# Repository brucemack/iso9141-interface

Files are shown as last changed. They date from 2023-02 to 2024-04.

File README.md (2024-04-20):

Overview
========
This is a KiCad project for a simple ISO-9141 interface board.  This allows a microcontroller to be interfaced to car's ISO-9141 (OBD2) port.

Please see related firmware projects:

* [The OBDII Reader](https://github.com/brucemack/hello-obd2)
* [The ECU Simulator](https://github.com/brucemack/ecu-sim)

[Here is the official ISO standard document](https://cdn.standards.iteh.ai/samples/16737/e6b719fd44c345a792656f6d19e6cee4/ISO-9141-1989.pdf) that explains all of the details of this interface. What makes this interesting is that the transmit/receive to/from the vehicle all happens on a single wire.

Send any questions to bruce at mackinnon dot com.

Interfaces (V2)
===============

J1 is the connection to the vehicle:
* Pin 1 - 12V battery power
* Pin 2 - KLINE
* Pin 3 - Ground

J2 is the connector to the microcontroller:
* Pin 1 - Data transmit (data from controller to vehicle)
* Pin 2 - Data receive (data from vehicle to controller)
* Pin 3 - Control line which allow the KLINE to be pulled low for the purposes of signalling
* Pin 4 - An indicator LED that can be used by the controller
* Pin 5 - +5V regulated power for controller
* Pin 6 - Ground

Hardware
========

The V2 PCB:

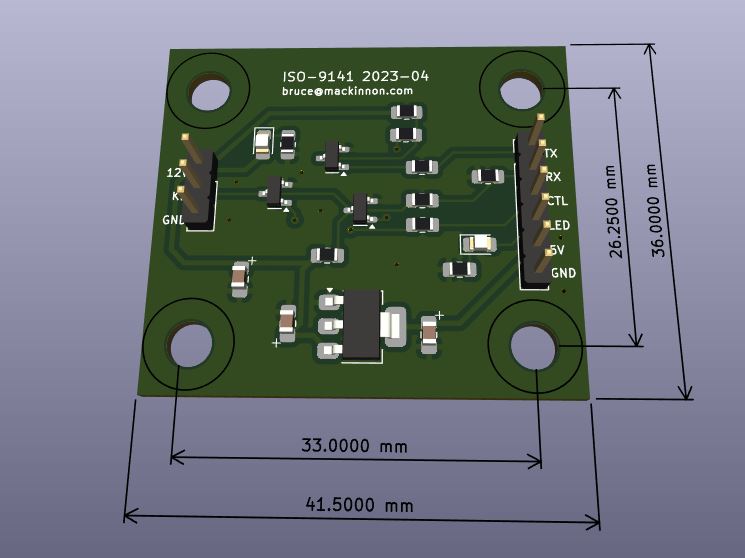
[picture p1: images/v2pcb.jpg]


Here's what it looks like in real life (V1):

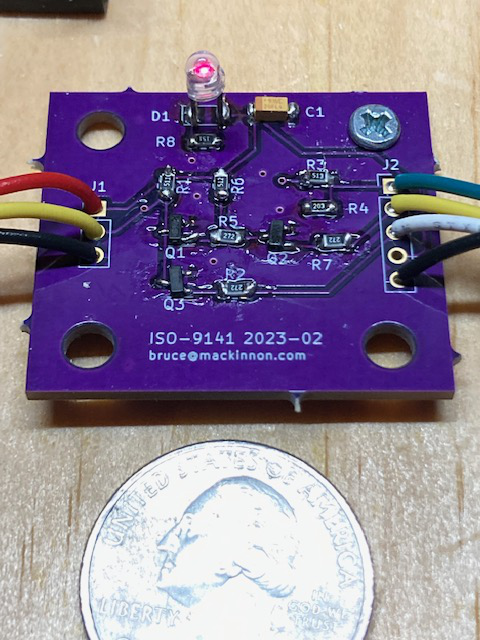
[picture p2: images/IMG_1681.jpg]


Connector Notes
===============

The scanner/instrument uses a SAE J1962 connector (male)
* [Cable](https://www.amazon.com/iKKEGOL-Connector-Diagnostic-Extension-Pigtail/dp/B0828YHWFG)
* [Just the Connector](https://www.sparkfun.com/products/9911)
* [Connector](https://www.amazon.com/Elecbee-Automobile-Connector-Shell-Diagnostic/dp/B0CKMSXCBY)

The vehicle uses a J1962F female connector like this: https://www.amazon.com/Goliton-Connection-Connector-Harness-Assembled/dp/B09NBWQLMQ

Copyright
=========

Copyright (C) 2024 - Bruce MacKinnon

This work is covered under the terms of the GNU Public License (V3). Please consult the LICENSE file for more information.

This work is being made available for non-commercial use. Redistribution, commercial use or sale of any part is prohibited.

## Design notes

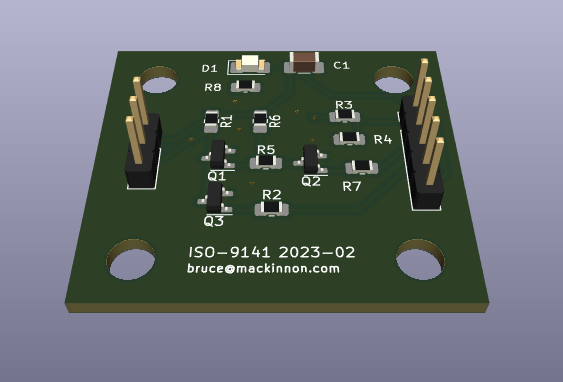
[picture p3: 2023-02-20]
images/SS1.png

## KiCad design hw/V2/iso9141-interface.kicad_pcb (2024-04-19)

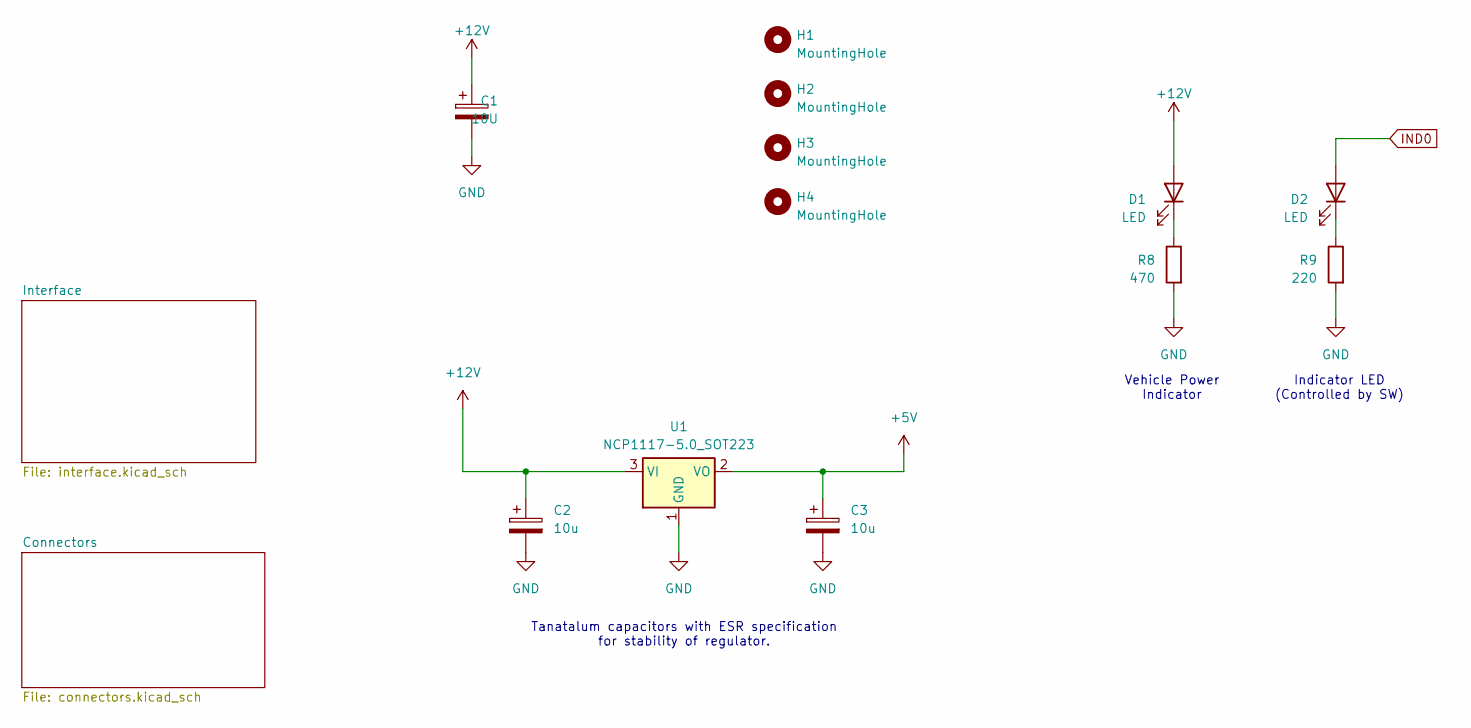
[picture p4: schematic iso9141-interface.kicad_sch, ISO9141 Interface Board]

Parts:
C1: 10U; CPOL_0805_2012Metric_Pad1.18x1.45mm_HandSolder
C2, C3: 10u; CPOL_0805_2012Metric_Pad1.18x1.45mm_HandSolder
D1, D2: LED; LED_0805_2012Metric_Pad1.15x1.40mm_HandSolder
H1, H2, H3, H4: MountingHole; MountingHole_4.3mm_M4
R8: 470; R_0805_2012Metric_Pad1.20x1.40mm_HandSolder
R9: 220; R_0805_2012Metric_Pad1.20x1.40mm_HandSolder
U1: NCP1117-5.0_SOT223; SOT-223-3_TabPin2

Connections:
+5V: C3.1, U1.2 (VO); also elsewhere on the board
+12V: C1.1, C2.1, D1.2 (A), U1.3 (VI); also elsewhere on the board
GND: C1.2, C2.2, C3.2, R8.2, R9.2, U1.1 (GND); also elsewhere on the board
IND0: D2.2 (A); also elsewhere on the board
unnamed: D1.1 (K), R8.1
unnamed: D2.1 (K), R9.1

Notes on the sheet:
Tanatalum capacitors with ESR specification for stability of regulator.
Indicator LED (Controlled by SW)
Vehicle Power Indicator

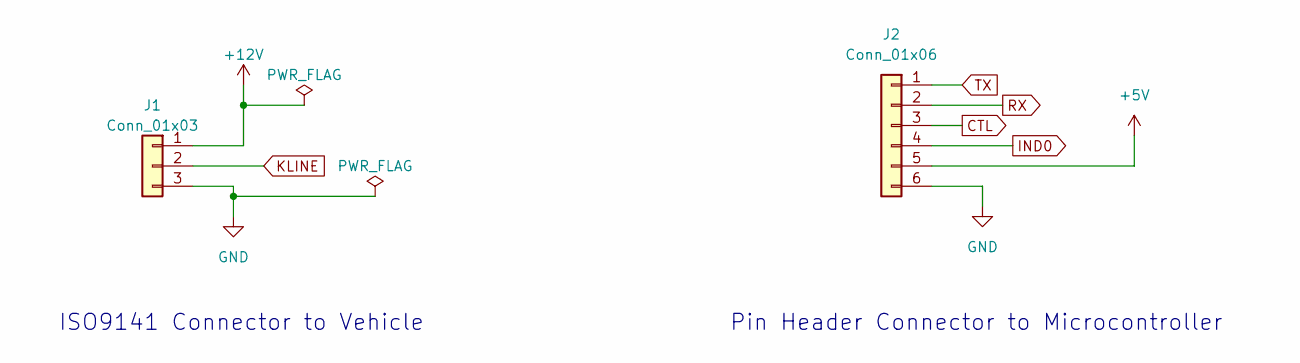
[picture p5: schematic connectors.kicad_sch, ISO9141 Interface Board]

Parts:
J1: Conn_01x03; PinHeader_1x03_P2.54mm_Vertical
J2: Conn_01x06; PinHeader_1x06_P2.54mm_Vertical

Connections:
+5V: J2.5; also elsewhere on the board
+12V: J1.1; also elsewhere on the board
CTL: J2.3; also elsewhere on the board
GND: J1.3, J2.6; also elsewhere on the board
IND0: J2.4; also elsewhere on the board
KLINE: J1.2; also elsewhere on the board
RX: J2.2; also elsewhere on the board
TX: J2.1; also elsewhere on the board

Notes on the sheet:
Pin Header Connector to Microcontroller
ISO9141 Connector to Vehicle

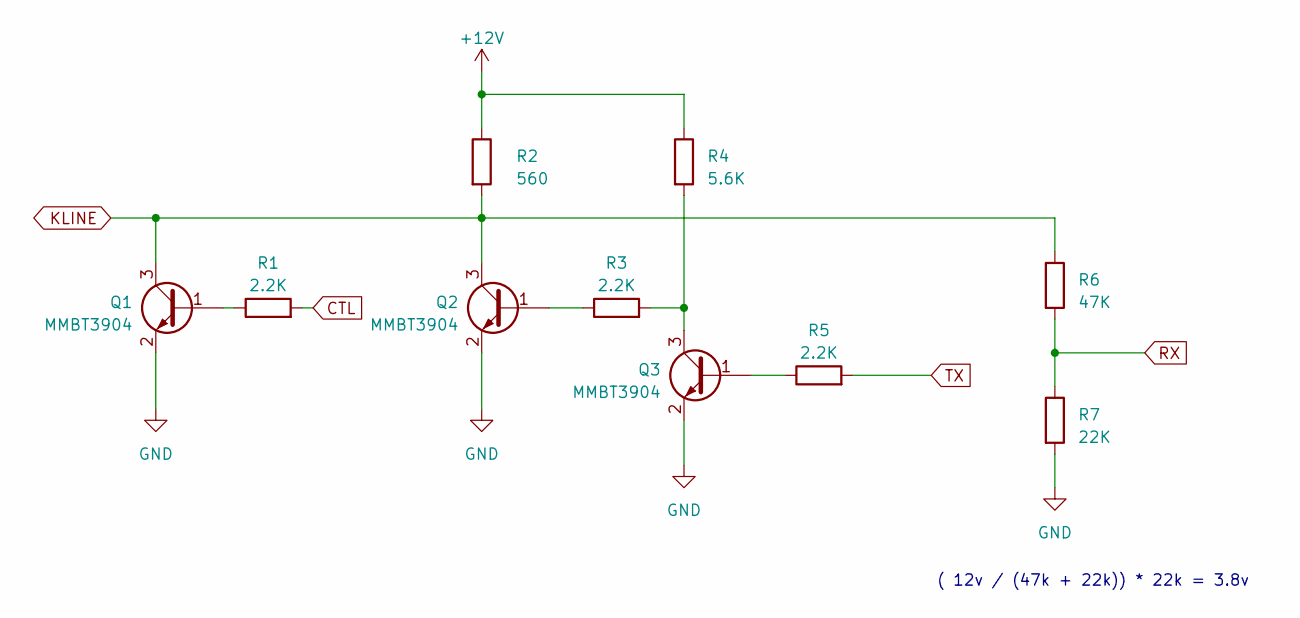
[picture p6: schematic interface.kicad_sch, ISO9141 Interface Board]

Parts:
Q1, Q2, Q3: MMBT3904; SOT-23
R1, R3, R5: 2.2K; R_0805_2012Metric_Pad1.20x1.40mm_HandSolder
R2: 560; R_0805_2012Metric_Pad1.20x1.40mm_HandSolder
R4: 5.6K; R_0805_2012Metric_Pad1.20x1.40mm_HandSolder
R6: 47K; R_0805_2012Metric_Pad1.20x1.40mm_HandSolder
R7: 22K; R_0805_2012Metric_Pad1.20x1.40mm_HandSolder

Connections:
+12V: R2.1, R4.1; also elsewhere on the board
CTL: R1.2; also elsewhere on the board
GND: Q1.2 (E), Q2.2 (E), Q3.2 (E), R7.2; also elsewhere on the board
KLINE: Q1.3 (C), Q2.3 (C), R2.2, R6.1; also elsewhere on the board
unnamed: Q1.1 (B), R1.1
unnamed: Q2.1 (B), R3.1
unnamed: Q3.1 (B), R5.1
unnamed: Q3.3 (C), R3.2, R4.2
RX: R6.2, R7.1; also elsewhere on the board
TX: R5.2; also elsewhere on the board

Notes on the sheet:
( 12v / (47k + 22k)) * 22k = 3.8v

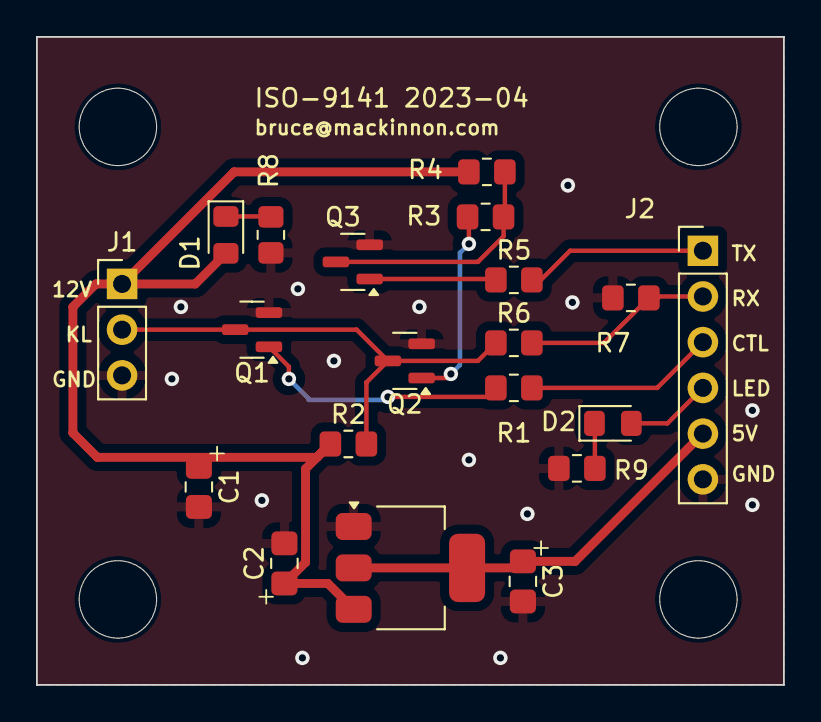
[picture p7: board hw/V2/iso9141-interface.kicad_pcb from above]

Board: 2 copper layers, 41.5 x 36.0 mm, 24 parts (0 on the bottom side), 14 nets.

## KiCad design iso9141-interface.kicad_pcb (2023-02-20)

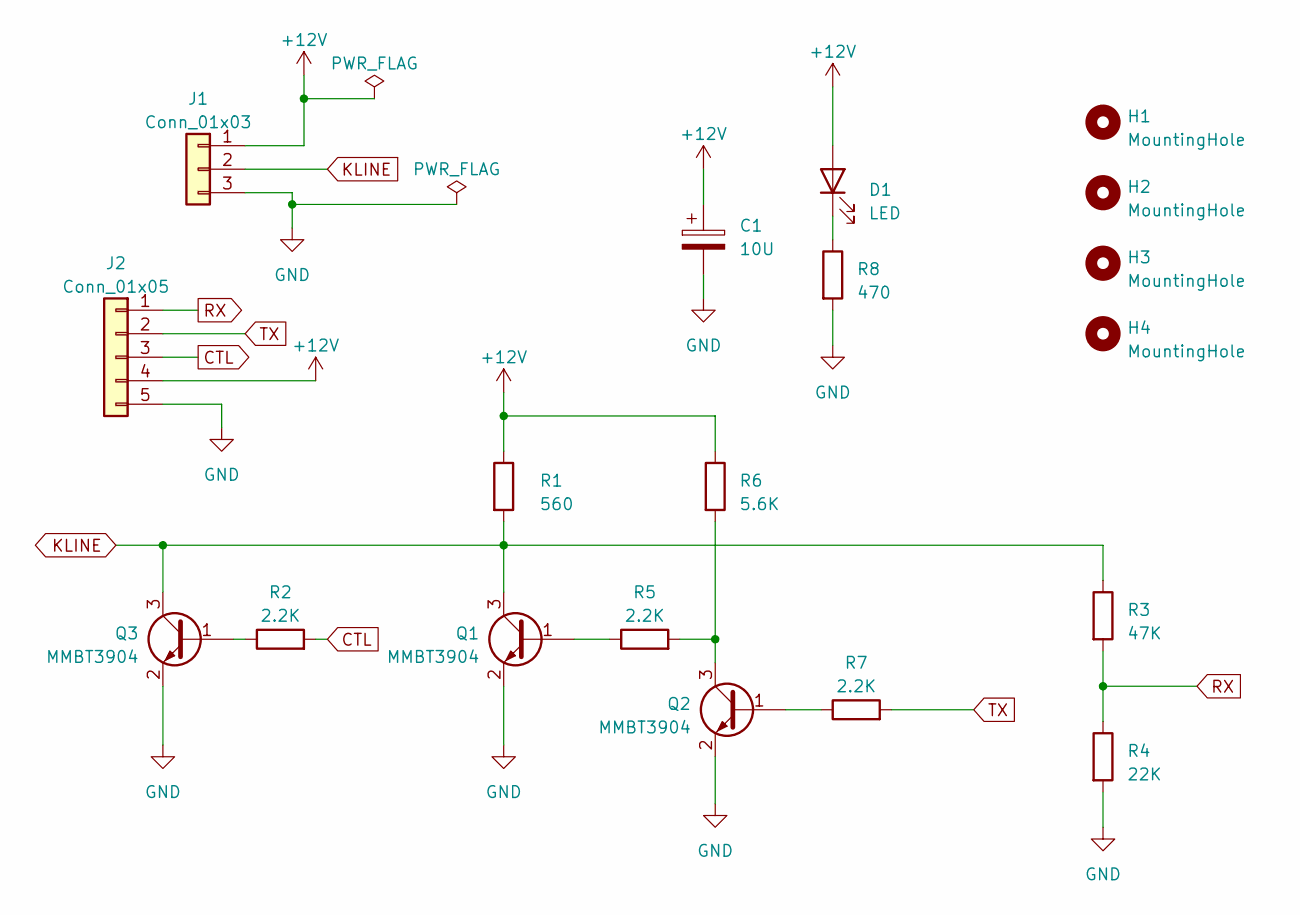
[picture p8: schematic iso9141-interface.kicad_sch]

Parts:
C1: 10U; C_1206_3216Metric_Pad1.33x1.80mm_HandSolder
D1: LED; LED_1206_3216Metric_Pad1.42x1.75mm_HandSolder
H1, H2, H3, H4: MountingHole; MountingHole_4.3mm_M4
J1: Conn_01x03; PinHeader_1x03_P2.54mm_Vertical
J2: Conn_01x05; PinHeader_1x05_P2.54mm_Vertical
Q1, Q2, Q3: MMBT3904; SOT-23
R1: 560; R_0805_2012Metric_Pad1.20x1.40mm_HandSolder
R2, R5, R7: 2.2K; R_0805_2012Metric_Pad1.20x1.40mm_HandSolder
R3: 47K; R_0805_2012Metric_Pad1.20x1.40mm_HandSolder
R4: 22K; R_0805_2012Metric_Pad1.20x1.40mm_HandSolder
R6: 5.6K; R_0805_2012Metric_Pad1.20x1.40mm_HandSolder
R8: 470; R_0805_2012Metric_Pad1.20x1.40mm_HandSolder

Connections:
+12V: C1.1, D1.2 (A), J1.1, J2.4, R1.1, R6.1
CTL: J2.3, R2.2
GND: C1.2, J1.3, J2.5, Q1.2 (E), Q2.2 (E), Q3.2 (E), R4.2, R8.2
KLINE: J1.2, Q1.3 (C), Q3.3 (C), R1.2, R3.1
unnamed: D1.1 (K), R8.1
unnamed: Q1.1 (B), R5.1
unnamed: Q2.1 (B), R7.1
unnamed: Q2.3 (C), R5.2, R6.2
unnamed: Q3.1 (B), R2.1
RX: J2.1, R3.2, R4.1
TX: J2.2, R7.2

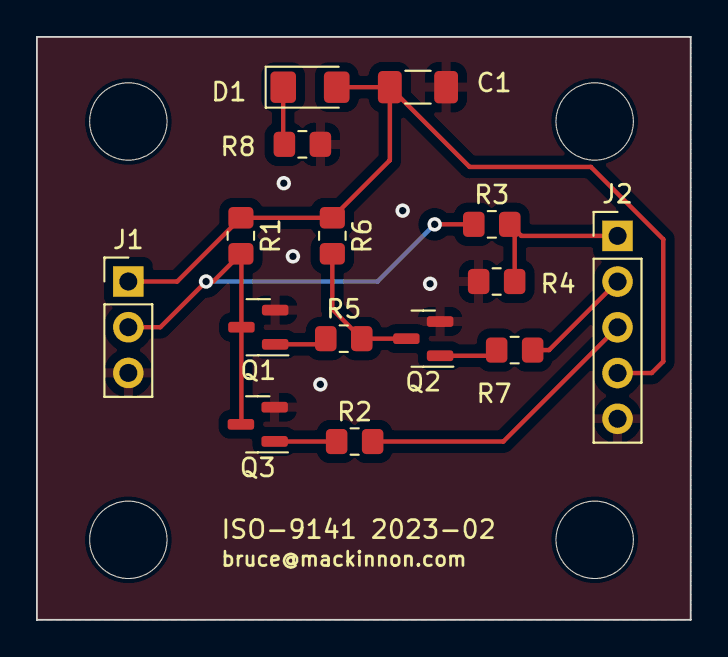
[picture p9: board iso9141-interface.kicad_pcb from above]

Board: 2 copper layers, 36.3 x 32.4 mm, 19 parts (0 on the bottom side), 11 nets.

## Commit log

2024-04-17 Commiting V2 files that were previously missing
    [connectors.kicad_sch, interface.kicad_sch, iso9141-interface.kicad_pcb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]
2024-04-19 Updated PCB for V2, sent to JLC
    [iso9141-interface.kicad_pcb]

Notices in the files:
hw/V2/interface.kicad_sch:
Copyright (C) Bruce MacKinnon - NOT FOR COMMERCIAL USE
